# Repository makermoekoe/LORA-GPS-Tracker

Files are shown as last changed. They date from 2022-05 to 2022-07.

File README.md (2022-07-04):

# LORA-GPS-Tracker

**This page is a work in progress!**

</a>

This LORA-GPS-Tracker was designed to just test three modules, which I haven't worked with yet: the RFM95 LORA module, the ESP32-S2-Mini module and the ATGM336h GPS module. All combined this device can be used as a GPS-Tracker for LORA based systems. Additionally to the modules, the board includes a 0.96" OLED display, two user buttons, a user RGB LED, a LiPo battery charger with a 16340 cell holder, and a dual LDO setup, which is very handy when it comes to deep sleeping.

Here are some specs of the board:
- ESP32-S2-Mini
- USB Type-C for charging the battery and flashing the ESP32
- Dual LDO setup, which will reduce the sleep current (the main power sinks can be shut down before entering a sleep mode)
- Power friendly OLED display
- Dimensions are 60x43mm

The [Youtube Video](https://youtu.be/C7jFupvuy9M) shows the PCB assembly process, some initial tests and some power measurements.

## Connections

The RFM95 LORA module is connected via SPI, the ATGM336h GPS module is connected via UART and the OLED display is connected via I2C.

GPIO ESP32 | Function | Mode
-------- | -------- | --------
GPIO1 | LORA_RST | Output
GPIO2 | LORA_MISO | Input
GPIO3 | LORA_MOSI | Output
GPIO4 | LORA_SCK | Output
GPIO5 | LORA_CS | Output
GPIO6 | LORA_INT | Input
GPIO7 | LORA_DIO1 | Data
GPIO8 | LORA_DIO2 | Data
GPIO12 | Button2 | Input
GPIO14 | Enable LDO2 | Output
GPIO15 | BAT_ADC | Input
GPIO16 | Button1 | Input
GPIO19 | USB_DN | Data
GPIO20 | USB_DP | Data
GPIO34 | OLED_RST | Output
GPIO35 | I2C_SCL | Output
GPIO36 | I2C_SDA | Data
GPIO37 | LED_CLK | Output
GPIO38 | LED_SDI | Data
GPIO40 | GPS_PPS | Input
GPIO41 | GPS_RXD | Input
GPIO42 | GPS_TXD | Output

By switching off the EN_LDO2 output, the second LDO which powers the GPS as well as LORA module, the onboard LED and the OLED display, will be shut down.

## Power measurements

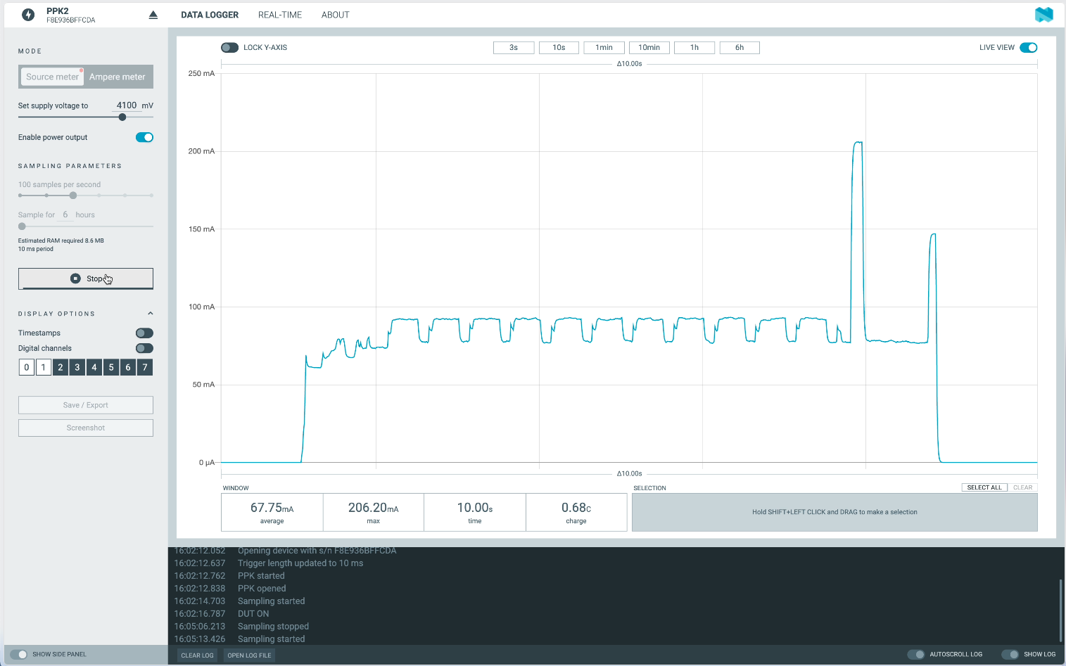
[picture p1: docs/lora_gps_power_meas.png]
</a>

State | Avg. current | Peak current
-------- | -------- | --------
Reading sensors | 80mA | 92mA
Transmitting LORA | 135mA | 208mA
Deep sleep | 75µA | 82µA

Note: The schematics in this repo have the I2C pull-up resistors connected to +3V3. It reduces the power consumption if you don't mount these resistors or if you connect them to VDD (controllable via LDO2).

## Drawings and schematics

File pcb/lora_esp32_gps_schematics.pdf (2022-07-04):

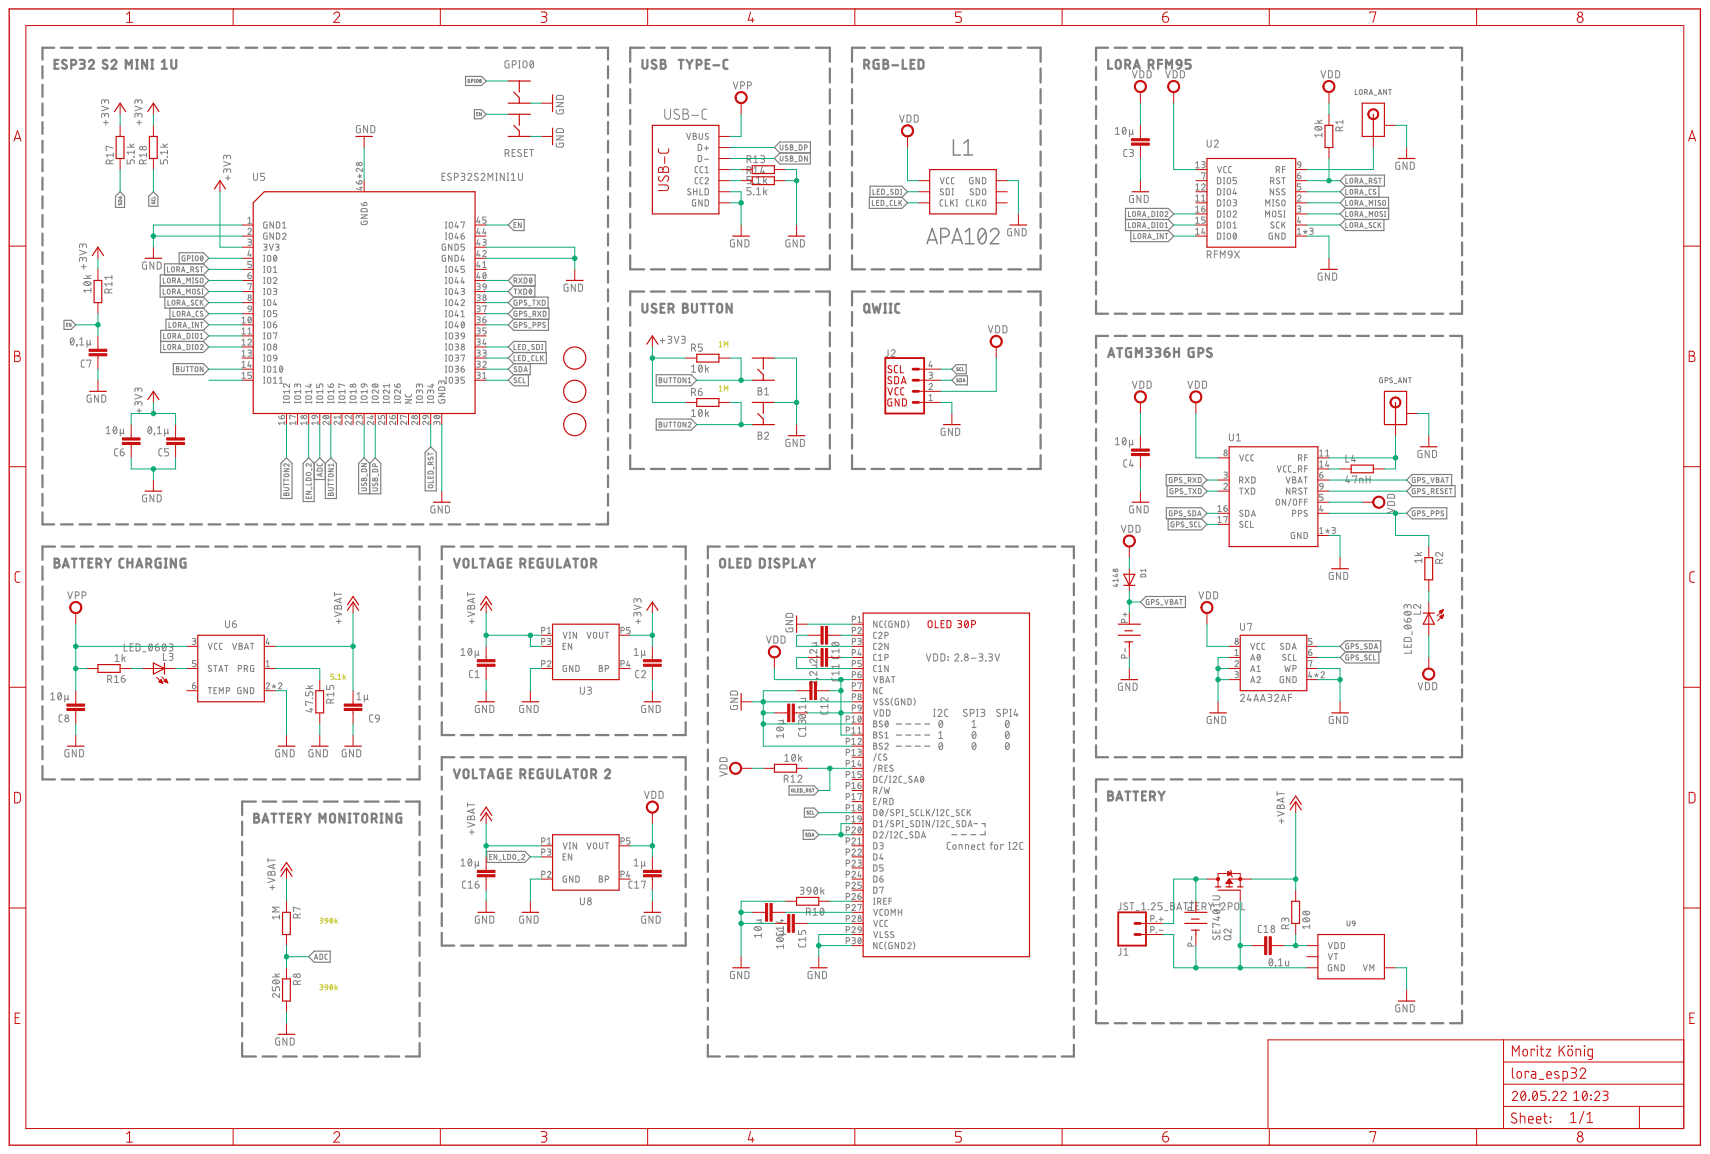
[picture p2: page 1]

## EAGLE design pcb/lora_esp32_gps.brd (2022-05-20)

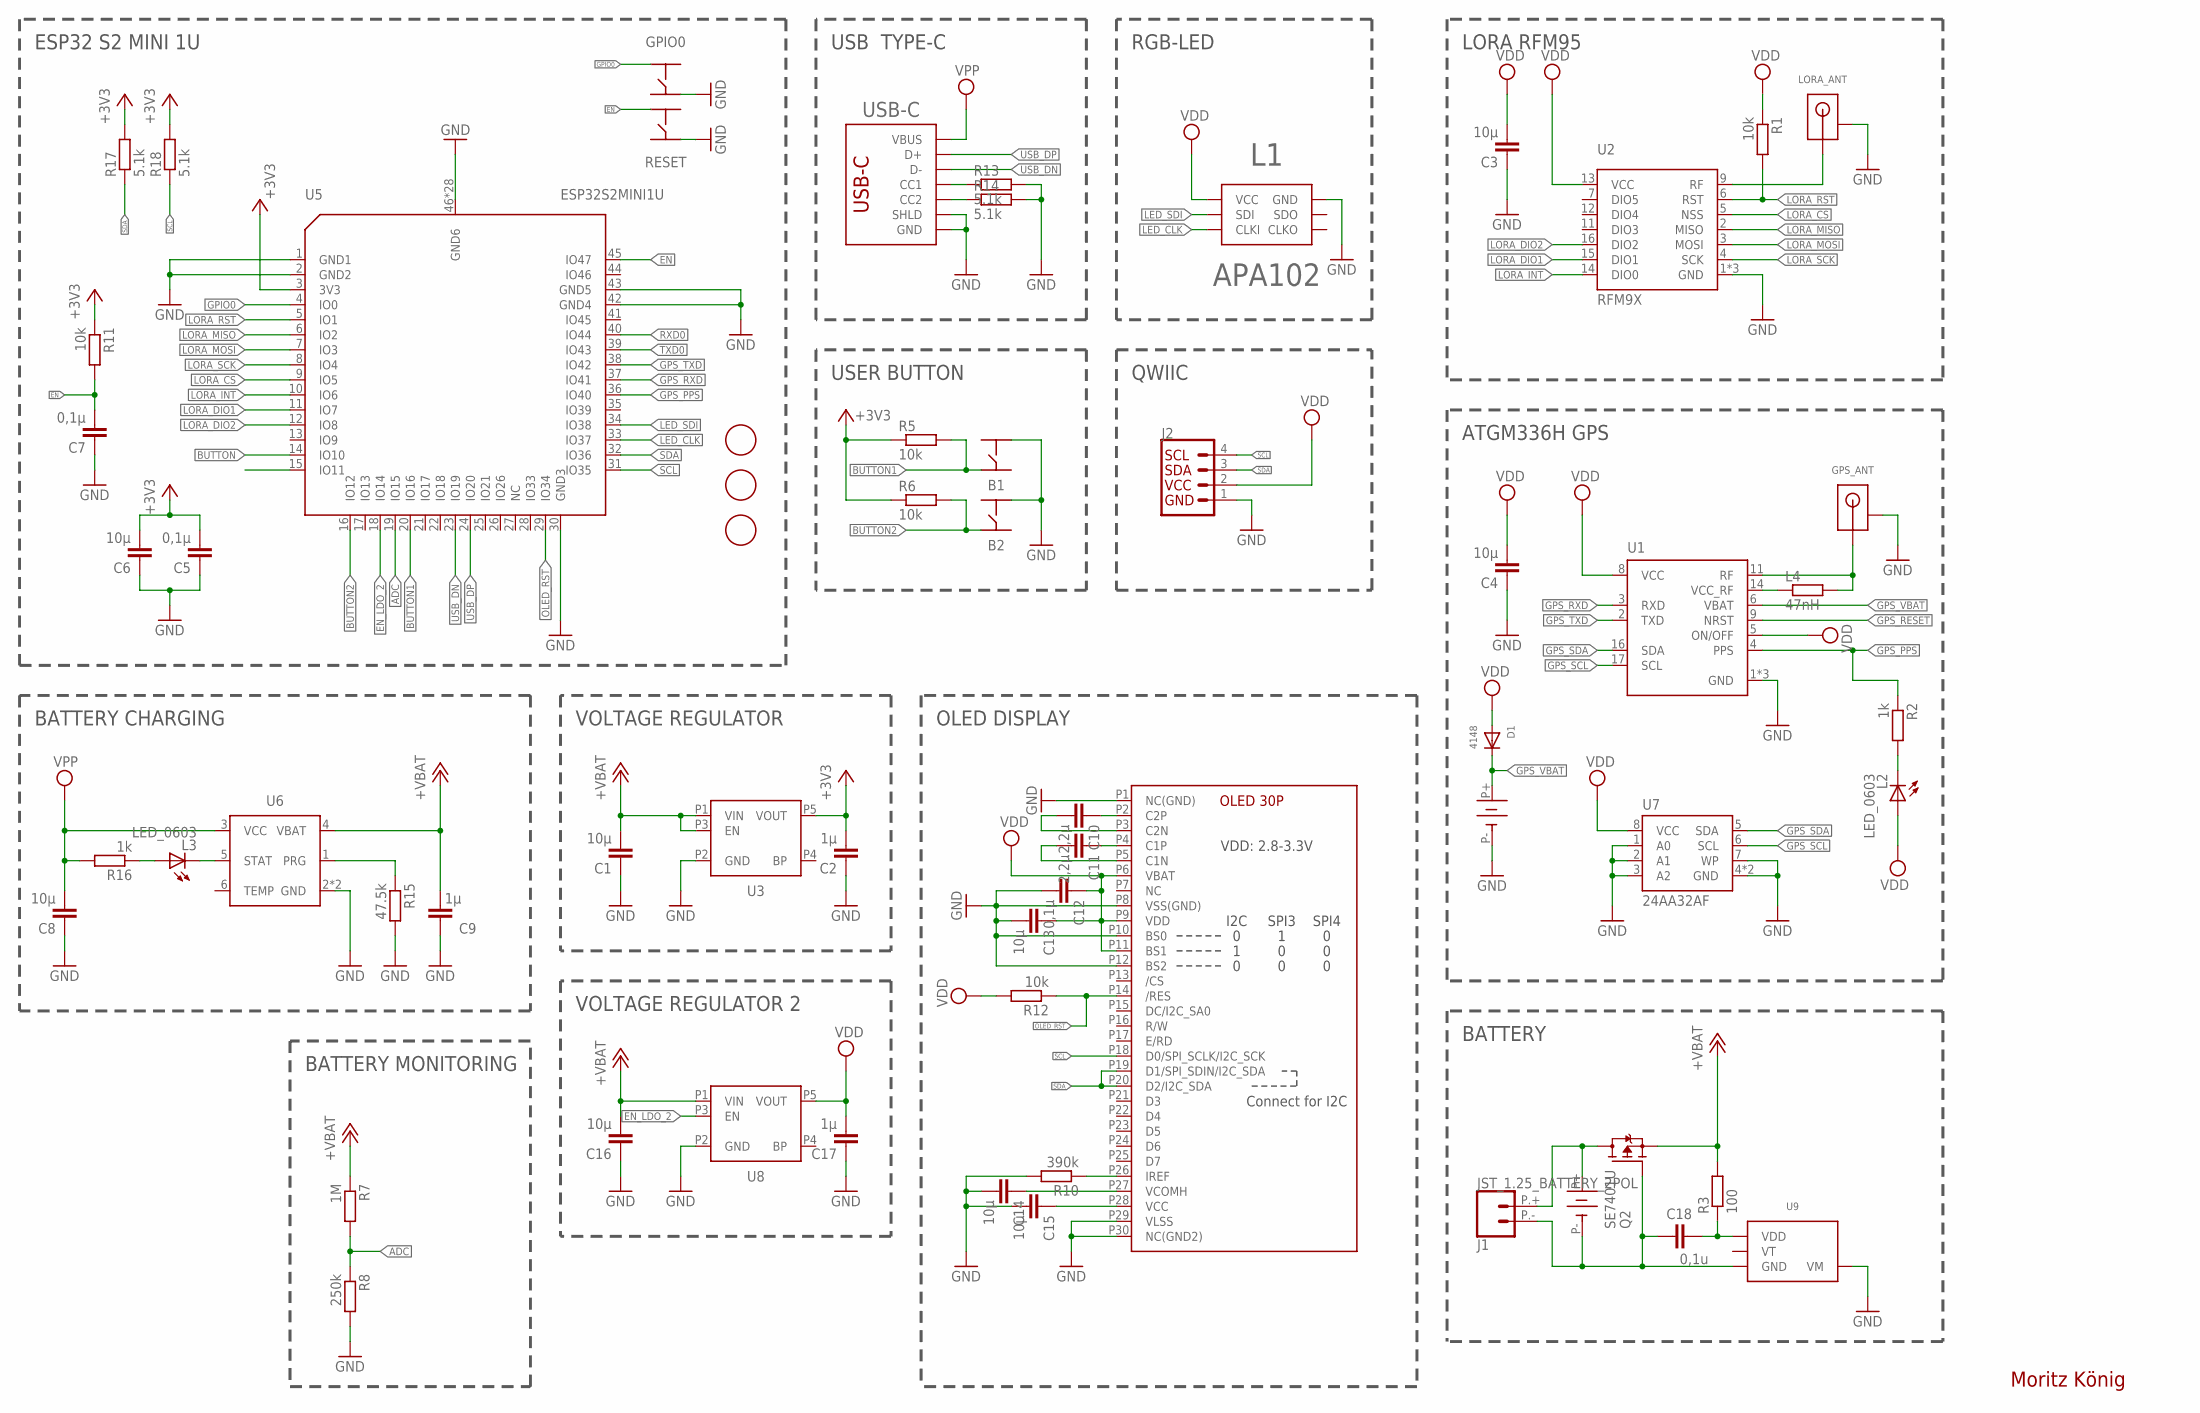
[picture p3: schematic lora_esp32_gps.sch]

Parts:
B1, B2: PTS840ESDGMSMTRLFS
BAT2: MS621
C1, C3, C4, C6, C8, C13, C14, C15, C16: 10µ; C0603
C2, C9, C17: 1µ; C0603
C5, C7, C12: 0,1µ; C0603
C10, C11: 2,2µ; C0603
C18: 0,1u; C0603
D1: 4148; SOD-323F
FID1, FID2, FID3: FIDUCIAL; FIDUCIAL_1MM
GPIO0: BUTTON_4PIN_TS_1177; TS-1177-C-B-B
GPS_ANT: UFL_ANT_CONNECTOR
J1: JST_1.25_BATTERY_2POL; JST_1.25MM_2POL
J2: QWIIC_CONNECTORJS-1MM; 1X04_1MM_RA
L1: APA102_2020
L2, L3: LED_0603; CHIPLED_0603
L4: 47nH; R0402
LORA_ANT: UFL_ANT_CONNECTOR
Q2: SE7401U; SOT323
R1, R5, R6, R11, R12: 10k; R0603
R2, R16: 1k; R0603
R3: 100; R0603
R7: 1M; R0603
R8: 250k; R0603
R10: 390k; R0603
R13, R14, R17, R18: 5.1k; R0603
R15: 47.5k; R0603
RESET: BUTTON_4PIN_TS_1177; TS-1177-C-B-B
U1: ATGM336H; ATGM336H-MODULE
U2: RFM9X; LORA_RFM9X
U3, U8: RT9193_SC70-5; SC-70-5
U4: OLD_096_SSD1306_30P_2B; OLED_096_30P_B
U5: ESP32S2MINI1U; ESP32-S2-MINI-1U
U6: WS4518D; DFN-6
U7: 24AA32AF; TDFN8
U9: XB5353A; SOT23-5
U$2: BATTERY_KEYSTONE_1051; KEYSTONE_1051
USB-C: USB_C_C393939; USBC_C393939

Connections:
+3V3: C2.2, C5.2, C6.2, R5.1, R6.1, R11.1, R17.2, R18.2, U3.P5 (VOUT), U5.3 (3V3)
+VBAT: C1.2, C9.2, C16.2, Q2.2 (S), R3.2, R7.1, U3.P1 (VIN), U3.P3 (EN), U6.4 (VBAT), U8.P1 (VIN)
ADC: R7.2, R8.1, U5.19 (IO15)
BUTTON: U5.14 (IO10)
BUTTON1: B1.2, R5.2, U5.20 (IO16)
BUTTON2: B2.2, R6.2, U5.16 (IO12)
EN: C7.2, R11.2, RESET.P4 (4), U5.45 (IO47)
EN_LDO_2: U5.18 (IO14), U8.P3 (EN)
GND: B1.3, B2.3, BAT2.P- (GND), C1.1, C2.1, C3.1, C4.1, C5.1, C6.1, C7.1, C8.1, C9.1, C12.2, C13.2, C14.2, C15.2, C16.1, C17.1, GPIO0.P1 (1), GPS_ANT.P1.- (GND), GPS_ANT.P2.- (GND), J2.1 (GND), L1.P6 (GND), L1.P6.1 (GND), LORA_ANT.P1.- (GND), LORA_ANT.P2.- (GND), R8.2, R10.2, R13.2, R14.2, R15.2, RESET.P1 (1), U1.1 (GND), U1.10 (GND), U1.12 (GND), U2.1 (GND), U2.8 (GND), U2.10 (GND), U3.P2 (GND), U4.P1 (NC(GND)), U4.P8 (VSS(GND)), U4.P10 (BS0), U4.P12 (BS2), U4.P29 (VLSS), U4.P30 (NC(GND2)), U5.1 (GND1), U5.2 (GND2), U5.30 (GND3), U5.42 (GND4), U5.43 (GND5), U5.46 (GND6), U5.47 (GND6), U5.48 (GND6), U5.49 (GND6), U5.50 (GND6), U5.51 (GND6), U5.52 (GND6), U5.53 (GND6), U5.54 (GND6), U5.55 (GND6), U5.56 (GND6), U5.57 (GND6), U5.58 (GND6), U5.59 (GND6), U5.60 (GND6), U5.61 (GND6), U5.62 (GND6), U5.63 (GND6), U5.64 (GND6), U5.65 (GND6), U5.66 (GND6), U5.67 (GND6), U5.68 (GND6), U5.69 (GND6), U5.70 (GND6), U5.71 (GND6), U5.72 (GND6), U5.73 (GND6), U6.2 (GND), U6.EXP (GND), U7.1 (A0), U7.2 (A1), U7.3 (A2), U7.4 (GND), U7.7 (WP), U7.EXP (GND), U8.P2 (GND), U9.4 (VM), U9.5 (VM), USB-C.A1B12 (GND), USB-C.B1A12 (GND), USB-C.S1 (SHLD), USB-C.S2 (SHLD), USB-C.S3 (SHLD), USB-C.S4 (SHLD)
GPIO0: GPIO0.P4 (4), U5.4 (IO0)
GPS_PPS: R2.1, U1.4 (PPS), U5.36 (IO40)
GPS_RESET: U1.9 (NRST)
GPS_RXD: U1.3 (RXD), U5.37 (IO41)
GPS_SCL: U1.17 (SCL), U7.6 (SCL)
GPS_SDA: U1.16 (SDA), U7.5 (SDA)
GPS_TXD: U1.2 (TXD), U5.38 (IO42)
GPS_VBAT: BAT2.P+ (VCC), D1.C, U1.6 (VBAT)
LED_CLK: L1.P5 (CLKI), U5.33 (IO37)
LED_SDI: L1.P4 (SDI), U5.34 (IO38)
LORA_CS: U2.5 (NSS), U5.9 (IO5)
LORA_DIO1: U2.15 (DIO1), U5.11 (IO7)
LORA_DIO2: U2.16 (DIO2), U5.12 (IO8)
LORA_INT: U2.14 (DIO0), U5.10 (IO6)
LORA_MISO: U2.2 (MISO), U5.6 (IO2)
LORA_MOSI: U2.3 (MOSI), U5.7 (IO3)
LORA_RST: R1.2, U2.6 (RST), U5.5 (IO1)
LORA_SCK: U2.4 (SCK), U5.8 (IO4)
unnamed: L4.1, U1.14 (VCC_RF)
unnamed: L2.P$1 (C), R2.2
unnamed: GPS_ANT.ANT, L4.2, U1.11 (RF)
unnamed: LORA_ANT.ANT, U2.9 (RF)
unnamed: C18.2, R3.1, U9.3 (VDD)
unnamed: C18.1, J1.P.- (2), Q2.1 (G), U9.2 (GND), U$2.P- (GND)
unnamed: R15.1, U6.1 (PRG)
unnamed: J1.P.+ (1), Q2.3 (D), U$2.P+ (VCC)
unnamed: R14.1, USB-C.B5 (CC2)
unnamed: C10.1, U4.P2 (C2P)
unnamed: C10.2, U4.P3 (C2N)
unnamed: C11.2, U4.P5 (C1N)
unnamed: R10.1, U4.P26 (IREF)
unnamed: R13.1, USB-C.A5 (CC1)
unnamed: C11.1, U4.P4 (C1P)
unnamed: C15.1, U4.P28 (VCC)
unnamed: C14.1, U4.P27 (VCOMH)
unnamed: L3.P$2 (A), R16.1
unnamed: L3.P$1 (C), U6.5 (STAT)
OLED_RST: R12.1, U4.P14 (/RES), U5.29 (IO34)
RXD0: U5.40 (IO44)
SCL: J2.4 (SCL), R18.1, U4.P18 (D0/SPI_SCLK/I2C_SCK), U5.31 (IO35)
SDA: J2.3 (SDA), R17.1, U4.P19 (D1/SPI_SDIN/I2C_SDA), U4.P20 (D2/I2C_SDA), U5.32 (IO36)
TXD0: U5.39 (IO43)
USB_DN: U5.23 (IO19), USB-C.A7 (D-), USB-C.B7 (D-)
USB_DP: U5.24 (IO20), USB-C.A6 (D+), USB-C.B6 (D+)
VDD: C3.2, C4.2, C12.1, C13.1, C17.2, D1.A, J2.2 (VCC), L1.P1 (VCC), L1.P1.1 (VCC), L2.P$2 (A), R1.1, R12.2, U1.5 (ON/OFF), U1.8 (VCC), U2.13 (VCC), U4.P6 (VBAT), U4.P9 (VDD), U4.P11 (BS1), U7.8 (VCC), U8.P5 (VOUT)
VPP: C8.2, R16.2, U6.3 (VCC), USB-C.A4B9 (VBUS), USB-C.B4A9 (VBUS)

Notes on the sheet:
Moritz König
BATTERY MONITORING
USB TYPE-C
VOLTAGE REGULATOR
RGB-LED
BATTERY CHARGING
BATTERY
USER BUTTON
OLED DISPLAY
QWIIC
ESP32 S2 MINI 1U
LORA RFM95
ATGM336H GPS
VOLTAGE REGULATOR 2

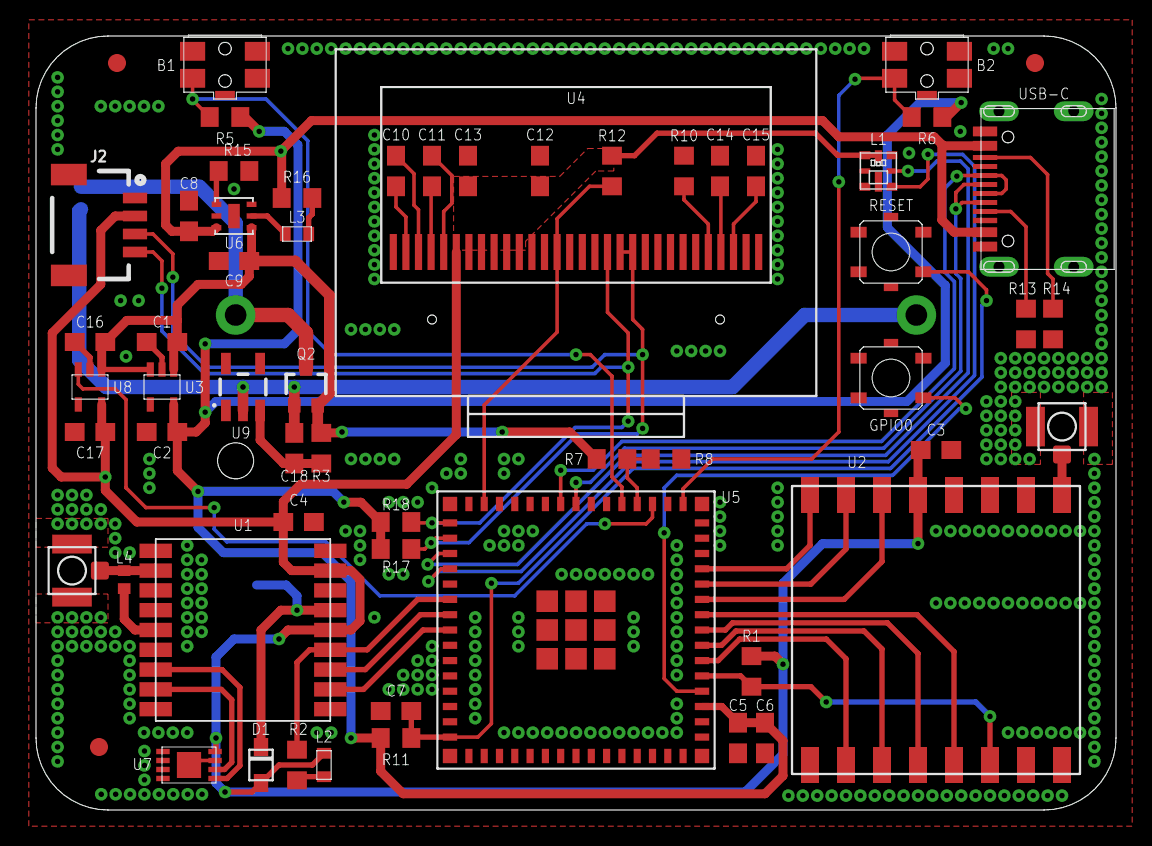
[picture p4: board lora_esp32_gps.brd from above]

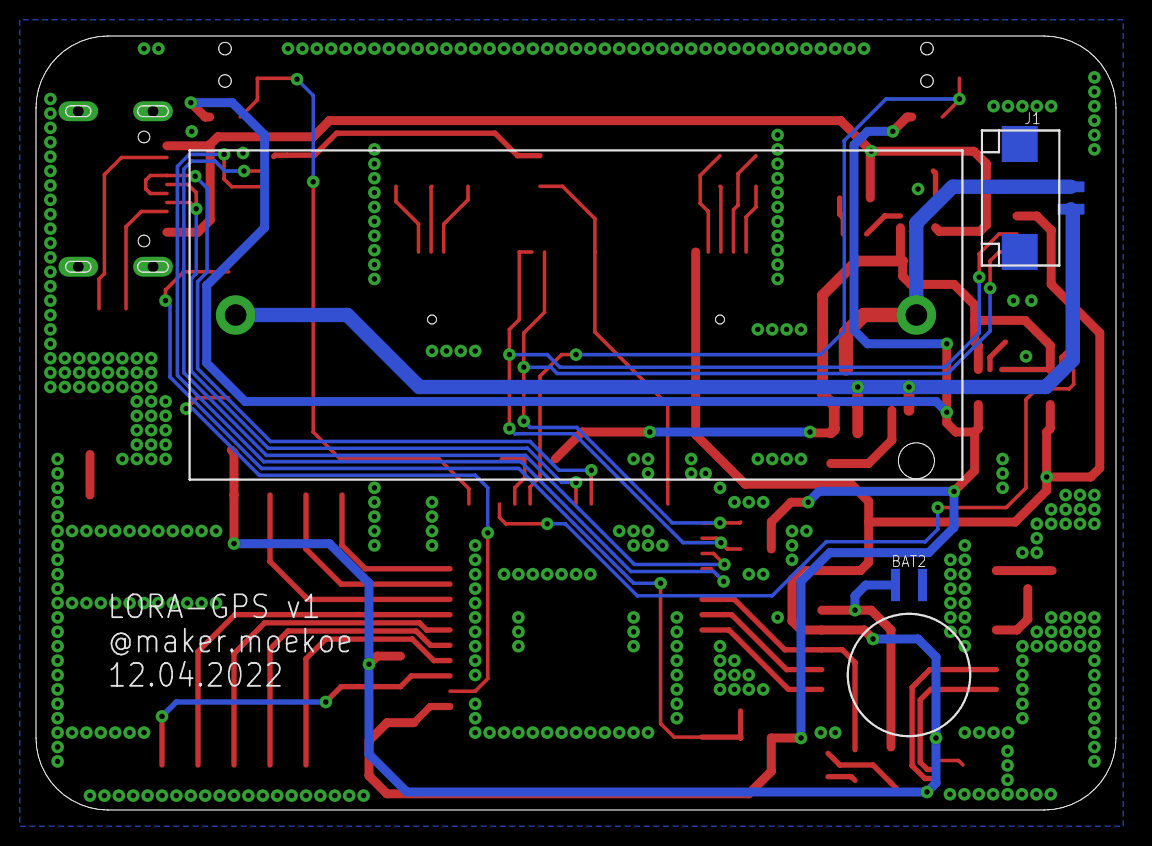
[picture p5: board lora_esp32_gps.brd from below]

Board: 2 copper layers, 60.0 x 43.0 mm, 63 parts (3 on the bottom side), 51 nets.

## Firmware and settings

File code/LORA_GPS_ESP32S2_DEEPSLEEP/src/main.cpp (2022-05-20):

#include <Arduino.h>
#include <FastLED.h>
// #include <WiFi.h>
#include <Wire.h>
#include <U8g2lib.h>
#include <SPI.h>
#include <LoRa.h>
#include <TinyGPS++.h>

#define APA102_SDI_PIN  38
#define APA102_CLK_PIN  37
#define BTN1_PIN        16
#define BTN2_PIN        12
#define EN_LDO2_PIN     14
#define ADC_PIN         15
#define OLED_RST_PIN    34

#define LORA_RST_PIN    1
#define LORA_MISO_PIN   2
#define LORA_MOSI_PIN   3
#define LORA_SCK_PIN    4
#define LORA_CS_PIN     5
#define LORA_INT_PIN    6
#define LORA_DIO1_PIN   7
#define LORA_DIO2_PIN   8

#define SDA_PIN_M       36
#define SCL_PIN_M       35

#define GPS_PPS_PIN     40
#define GPS_RXD_PIN     42
#define GPS_TXD_PIN     41


#define NUM_LEDS        1
CRGB leds[NUM_LEDS];

#define WIDTH 128
#define HEIGHT 64
U8G2_SSD1306_128X64_NONAME_F_HW_I2C u8g2(U8G2_R0, /* reset=*/ OLED_RST_PIN, /* clock=*/ SCL_PIN_M, /* data=*/ SDA_PIN_M);

const char* ssid = "XXX";
const char* password = "XXX";


TinyGPSPlus gps;
float lattitude,longitude;

unsigned long lora_sent_at = 0;
bool gps_pps_state = true;
unsigned long gps_pps_delay = 0;
unsigned long gps_last_pps_signal = 0;


float counter = 0;

// 100%, 95%, 90%, 85%, ...
int battery_percentage[] = {4200, 4150, 4110, 4080, 4020, 3980, 3950, 3910, 3870, 3850, 3840, 3820, 3800, 3790, 3770, 3750, 3730, 3710, 3690, 3610, 3270};

float get_battery_voltage(){
  int sum = 0;
  for(int i=0; i<100; i++) {
    sum = sum + analogRead(ADC_PIN);
  }
  float result = sum/100.0;
  return result * (1.3665);
}

int get_battery_percentage(float mv){
  int battery_mv = int(mv);
  int perc = 0;
  for(int i=0; i<=20; i++) if(battery_mv > battery_percentage[20-i]) perc+=5;
  return constrain(perc, 0, 100);
}


String get_gps_time(){
  int h, m, s;
  String gps_time = "";
  if(gps.time.isValid()){
    h = (gps.time.hour() + 2) % 24;
    m = gps.time.minute();
    s = gps.time.second();

    if(h<10) gps_time += "0";
    gps_time += String(h);
    gps_time += ":";
    if(m<10) gps_time += "0";
    gps_time += String(m);
    gps_time += ":";
    if(s<10) gps_time += "0";
    gps_time += String(s);
  }
  else{
    gps_time = "invalid";
  }
  return gps_time;
}

String get_gps_date(){
  int y, mo, d;
  String gps_date = "";
  if(gps.time.isValid()){
    y = gps.date.year();
    mo = gps.date.month();
    d = gps.date.day();

    if(d<10) gps_date += "0";
    gps_date += String(d);
    gps_date += ".";
    if(mo<10) gps_date += "0";
    gps_date += String(mo);
    gps_date += ".";
    gps_date += String(y);
  }
  else{
    gps_date = "invalid";
  }
  return gps_date;
}

// Set used fonts with width and height of each character
struct fonts {
  const uint8_t* font;
  int width;
  int height;
};

fonts font_xl = {u8g2_font_profont29_mf, 16, 19};
fonts font_m = {u8g2_font_profont17_mf, 9, 11};
fonts font_s = {u8g2_font_profont12_mf, 6, 8};
fonts font_xs = {u8g2_font_profont10_mf, 5, 6};

// Custom type to set up a page on the OLED display. Baisc structure is a page of three fields.
// A top one with the power, a left one with the voltage and a right one with the current.
struct display_page {
  String title;
  float *value;
  String msg;
  bool is_value;
};

float val1 = 0.0;
float placeholder = 0.0;
String msg2display_top = "";
String msg2display_bot = "";

display_page page_1 = {"Counter", &counter, "", true};
display_page page_2 = {"Test", &val1, "", true};

// Menu and Pages
#define N_PAGES 2
int current_page = 0;
bool new_page = true;
unsigned long t_new_page = 0;

struct page {
  int p;
  display_page &page;
};

page pages[N_PAGES] = {
  {0, page_1},
  {1, page_2},
};

// Alignment for the OLED display
enum box_alignment {
  Center,
  Left,
  Right
};

// Custom type for setting up a box which can be drawn to the oled display. It is defined by
// the top left corner and the width and height of the box.
struct box {
  int32_t left, top, width, height;
  int32_t radius;
  bool has_frame;

  void draw(bool fill) {
    int frame = has_frame ? 4 : 0;
    if (fill) u8g2.drawRBox(left + frame, top + frame, width - (2*frame), height - (2*frame), radius);
    else u8g2.drawRFrame(left, top, width, height, radius);
  }

  void print_text(String str, fonts f, box_alignment align, float pos) {
    u8g2.setFont(f.font);
    int x = 0;
    if(align == Center) x = left + 0.5 * (width - (f.width * str.length() - 1));
    else if(align == Left) x = left + 5;
    else if(align == Right) x = left + width - f.width * str.length() - 5;
    u8g2.setCursor(x, top + pos * height + f.height / 2);
    u8g2.print(str);
  }
};

// Initialize the boxes for the OLED
box top_left = {0, 0, 64, 10, 0, false};
box row1 = {0, 0, 128, 10, 0, false};
box row2 = {0, row1.top + row1.height, 128, row1.height, 0, false};
box row3 = {0, row2.top + row2.height, 128, row1.height, 0, false};
box row4 = {0, row3.top + row3.height, 128, row1.height, 0, false};
box row5 = {0, row4.top + row4.height, 128, row1.height, 0, false};
box row6 = {0, row5.top + row5.height, 128, row1.height, 0, false};

// Update the OLED display with the three boxes according to the given pages
void update_display(){
  u8g2.clearBuffer();

  if(new_page){
    if(millis() <= t_new_page + 800){
      top_left.print_text(pages[current_page].page.title, font_m, Center, 0.5);
    }
    else{
      new_page = false;
    }
  }

  if(!new_page){

    float bat_voltage = get_battery_voltage();
    String str0 = "Time: " + get_gps_time() + ", " + String(counter, 0);
    String str1 = "Date: " + get_gps_date();
    String str2 = "Battery: " + String(bat_voltage, 0) + "mV, " + String(get_battery_percentage(bat_voltage)) + "%";
    String str3 = "Loc: " + (gps.location.isValid() ? (String(gps.location.lat(), 6) + ", " + String(gps.location.lng(), 6)) : "invalid");
    String str4 = "Lora sent at: " + String(lora_sent_at);
    String str5 = "PPS delay: " + String(gps_pps_delay) + ", Sat: " + String(gps.satellites.value());

    row1.print_text(str0, font_xs, Center, 0.5);
    row2.print_text(str1, font_xs, Center, 0.5);
    row3.print_text(str2, font_xs, Center, 0.5);
    row4.print_text(str3, font_xs, Center, 0.5);
    row5.print_text(str4, font_xs, Center, 0.5);
    row6.print_text(str5, font_xs, Center, 0.5);
  }
  u8g2.sendBuffer();
}

void displayInfo(){
  Serial.print(F("Location: "));
  if (gps.location.isValid()){
    Serial.print(gps.location.lat(), 6);
    Serial.print(F(","));
    Serial.print(gps.location.lng(), 6);
  }
  else{
    Serial.print(F("INVALID"));
  }
  Serial.println();
}



void setup() {
  Serial.begin(115200);
  Serial1.begin(9600, SERIAL_8N1, GPS_RXD_PIN, GPS_TXD_PIN, false);

  pinMode(EN_LDO2_PIN, OUTPUT);
  digitalWrite(EN_LDO2_PIN, HIGH);

  pinMode(GPS_PPS_PIN, INPUT);
  pinMode(BTN1_PIN, INPUT);
  pinMode(BTN2_PIN, INPUT);
  pinMode(ADC_PIN, INPUT);
  analogReadResolution(12);

  delay(100);
  FastLED.addLeds<APA102, APA102_SDI_PIN, APA102_CLK_PIN, BGR>(leds, NUM_LEDS);
  FastLED.setBrightness(200);
  delay(100);

  leds[0] = CRGB::Green;
  FastLED.show();

  SPI.begin(LORA_SCK_PIN, LORA_MISO_PIN, LORA_MOSI_PIN, LORA_CS_PIN);
  LoRa.setPins(LORA_CS_PIN, LORA_RST_PIN, LORA_DIO1_PIN);

  if (!LoRa.begin(866E6)) {
    Serial.println("LoRa fail!");
    while (1);
  }
  Serial.println("LoRa OK!");

  Wire.begin(SDA_PIN_M, SCL_PIN_M);
  delay(100);
  u8g2.begin();
  delay(100);
  u8g2.clearBuffer();
  u8g2.sendBuffer();
}

unsigned long t_display = millis() + 100;
unsigned long t_send = millis() + 500;
unsigned long t_pps = millis() + 600;
unsigned long t_lora_send = millis() + 800;

void loop() {
  if (Serial1.available() > 0){
     if (gps.encode(Serial1.read())){
        // displayInfo();
     }
  }

  if(digitalRead(GPS_PPS_PIN) == 1 && gps_pps_state){
    gps_pps_delay = millis() - gps_last_pps_signal;
    gps_last_pps_signal = millis();
    String pps_str = "PPS delay: " + String(gps_pps_delay);
    Serial.println(pps_str);
    gps_pps_state = false;
  }
  else if(digitalRead(GPS_PPS_PIN) == 0 && !gps_pps_state){
    gps_pps_state = true;
  }

  if(millis() >= t_display + 1000){
    t_display = millis();
    update_display();
    counter++;
    int bat_voltage = get_battery_voltage();
    Serial.print(bat_voltage);
    Serial.print("\t");
    Serial.println(get_battery_percentage(bat_voltage));
  }

  if(digitalRead(BTN1_PIN) == 0){
    leds[0] = CRGB(0,0,100);
    FastLED.show();
    while(digitalRead(BTN1_PIN) == 0) delay(10);

    delay(500);
    digitalWrite(EN_LDO2_PIN, LOW);
    esp_sleep_enable_timer_wakeup(20000000);
    esp_sleep_enable_ext0_wakeup(GPIO_NUM_16, 0);
    esp_deep_sleep_start();

    leds[0] = CRGB(0,0,0);
    FastLED.show();
  }

  if(digitalRead(BTN2_PIN) == 0){
    leds[0] = CRGB(0,100,0);
    FastLED.show();

    String str = "Hey there at " + String(millis());
    lora_sent_at = millis();

    LoRa.beginPacket();
    LoRa.print(str);
    LoRa.endPacket();

    while(digitalRead(BTN2_PIN) == 0) delay(10);
    leds[0] = CRGB(0,0,0);
    FastLED.show();
  }

  if(millis() >= t_lora_send + 10000 && true){
    t_lora_send = millis();
    lora_sent_at = millis();

    String gps_time = get_gps_time();
    String gps_date = get_gps_date();
    float lat = gps.location.isValid() ? gps.location.lat() : 0;
    float lng = gps.location.isValid() ? gps.location.lng() : 0;
    int bat_voltage = get_battery_voltage();
    int bat_perc = get_battery_percentage(bat_voltage);


    String str_lora = "LORA;GT-" + String(gps_time) + ";GD-" + String(gps_date) + ";GLAT-" + String(lat, 6) +
      + ";GLNG-" + String(lng, 6) + ";BV-" + String(bat_voltage) + ";BP-" + String(bat_perc) + ";#";

    Serial.print("Send package: ");
    Serial.println(str_lora);

    LoRa.beginPacket();
    LoRa.print(str_lora);
    LoRa.endPacket();
  }
}

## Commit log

2022-05-20 initial commit with PCB and test code
    [lora_esp32_gps.brd, lora_esp32_gps.sch]
2022-07-04 added description and power measurements
2022-07-04 added schematics

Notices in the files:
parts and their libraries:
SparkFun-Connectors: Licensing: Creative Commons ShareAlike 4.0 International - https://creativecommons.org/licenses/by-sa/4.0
